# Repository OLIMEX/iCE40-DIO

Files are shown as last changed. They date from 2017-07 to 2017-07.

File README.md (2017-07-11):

# iCE40-DIO
Extension module for iCE40HX1K-EVB or iCE40HX8K-EVB.

iCE40-DIO adds 28 GPIOs to existing iCE40 boards. These signals can be set as inputs or outputs. 
The boards has a programmable DAC which can set the input voltage logic from 1.65 to 5.5V.

You can use the exported PDFs to access the schematic or the bill of materials. 

We used the latest KiCad night builds to create the design. Please use a new version KiCad to open it. 

License information should be found in LICENSE.txt

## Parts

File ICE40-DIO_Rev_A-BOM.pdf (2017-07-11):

ICE40-DIO_Rev_A | 08.04.2016
Quantity | Designation | Package | Designator
4 | 22uF/6.3V/0603 | C_0603 | C1,C3,C4,C6
10 | 100nF | C_0402 | C12,C13,C15,C2,C5,C10,C8,C9,C11,C14
1 | NA(100nF) | C_0402 | C7
2 | 2.2k | R_0402 | R1,R3
6 | 10k | R_0402 | R2,R4,R8,R9,R10,R11
1 | 10k/1% | R_0402 | R6
2 | 100k/1% | R_0402 | R5,R7
1 | FB0805/600R/2A | L_0805 | L1
1 | 1N5819(S4SOD-123) | SOD-123 | D1
2 | 74ALVC164245DL(SSOP48) | SSOP48 | U2,U3
1 | MCP1825-ADJE/DC(SOT-223-5) | SOT-223-5 | VR1
1 | MCP47A1T-A0E/LT(SC70-6) | SC70-6 | U1
4 | HN1x2(Opened) | HN1x2 | DIR1,DIR2,DIR3,DIR4
1 | BH10S | BH10S | UEXT1
1 | BH14S | BH14S | EXT1
1 | BH20S | BH20S | EXT2
1 | BH34R | BH34R | GPIO_Out1
1 | IDC34R | IDC34R_PCB | GPIO_In1

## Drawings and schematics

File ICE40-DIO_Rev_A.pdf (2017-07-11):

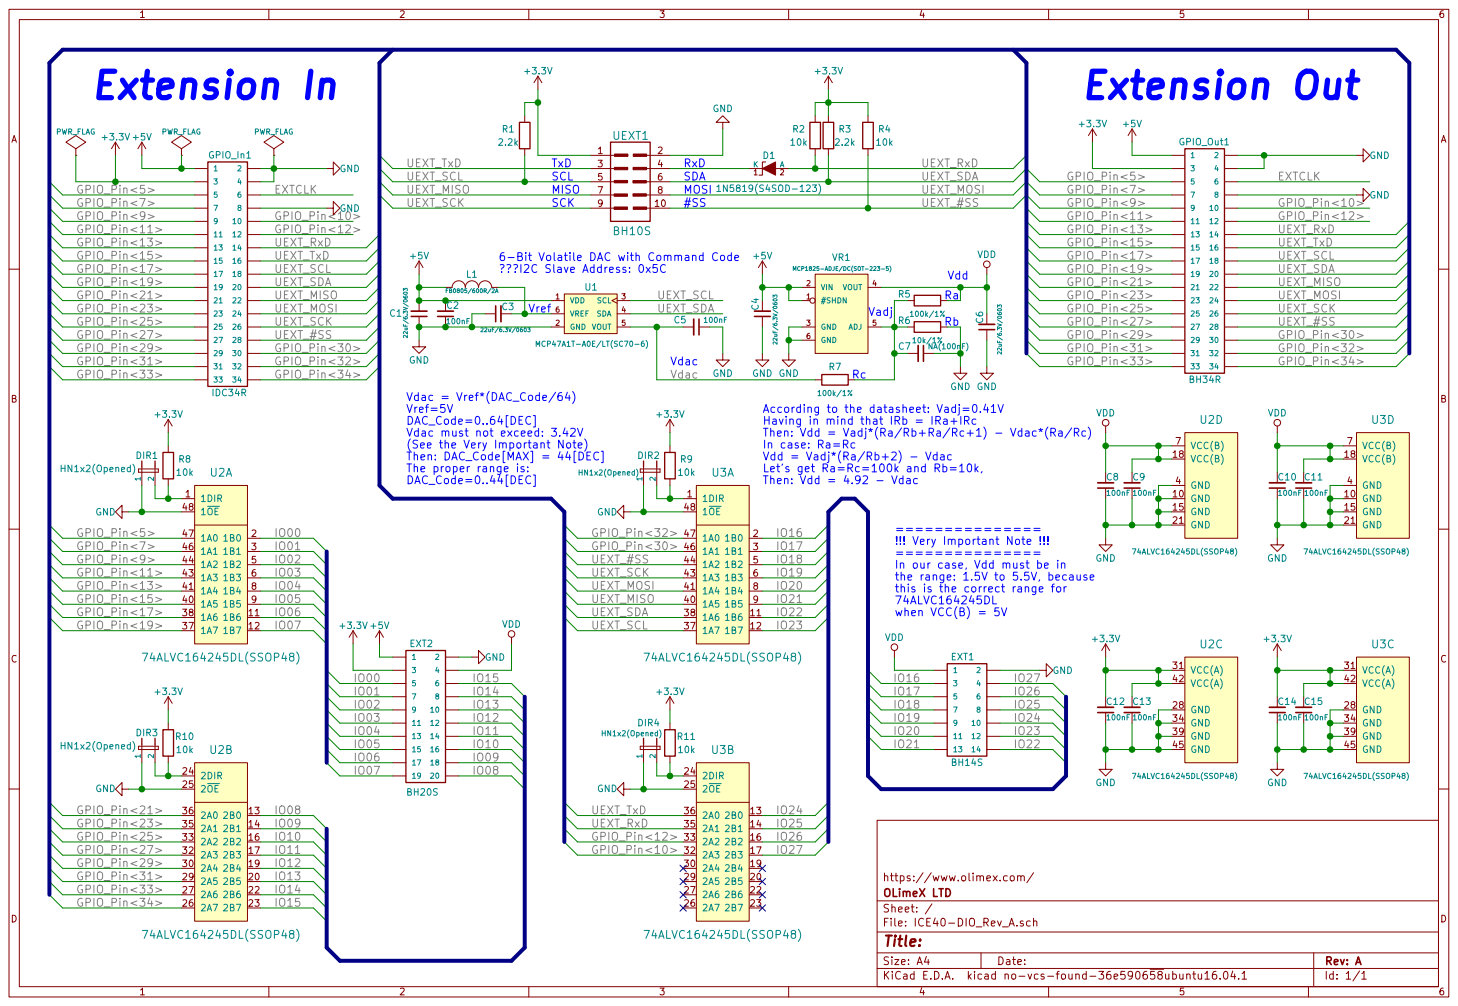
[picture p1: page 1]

6-Bit Volatile DAC with Command Code
I2C Slave Address: 0x5C

100k/1% According to the datasheet: Vadj=0.41V

Having in mind that IRb = IRa+IRc
Then: Vdd = Vadj*(Ra/Rb+Ra/Rc+1) - Vdac*(Ra/Rc)
In case: Ra=Rc Vdd = Vadj*(Ra/Rb+2) - Vdac

(See the Very Important Note)
Then: DAC_Code[MAX] = 44[DEC]
The proper range is:

!!! Very Important Note !!! ===============
In our case, Vdd must be in
the range: 1.5V to 5.5V, because
this is the correct range for
74ALVC164245DL
when VCC(B) = 5V

https://www.olimex.com/
File: ICE40-DIO_Rev_A.sch Sheet: / OLimeX LTD

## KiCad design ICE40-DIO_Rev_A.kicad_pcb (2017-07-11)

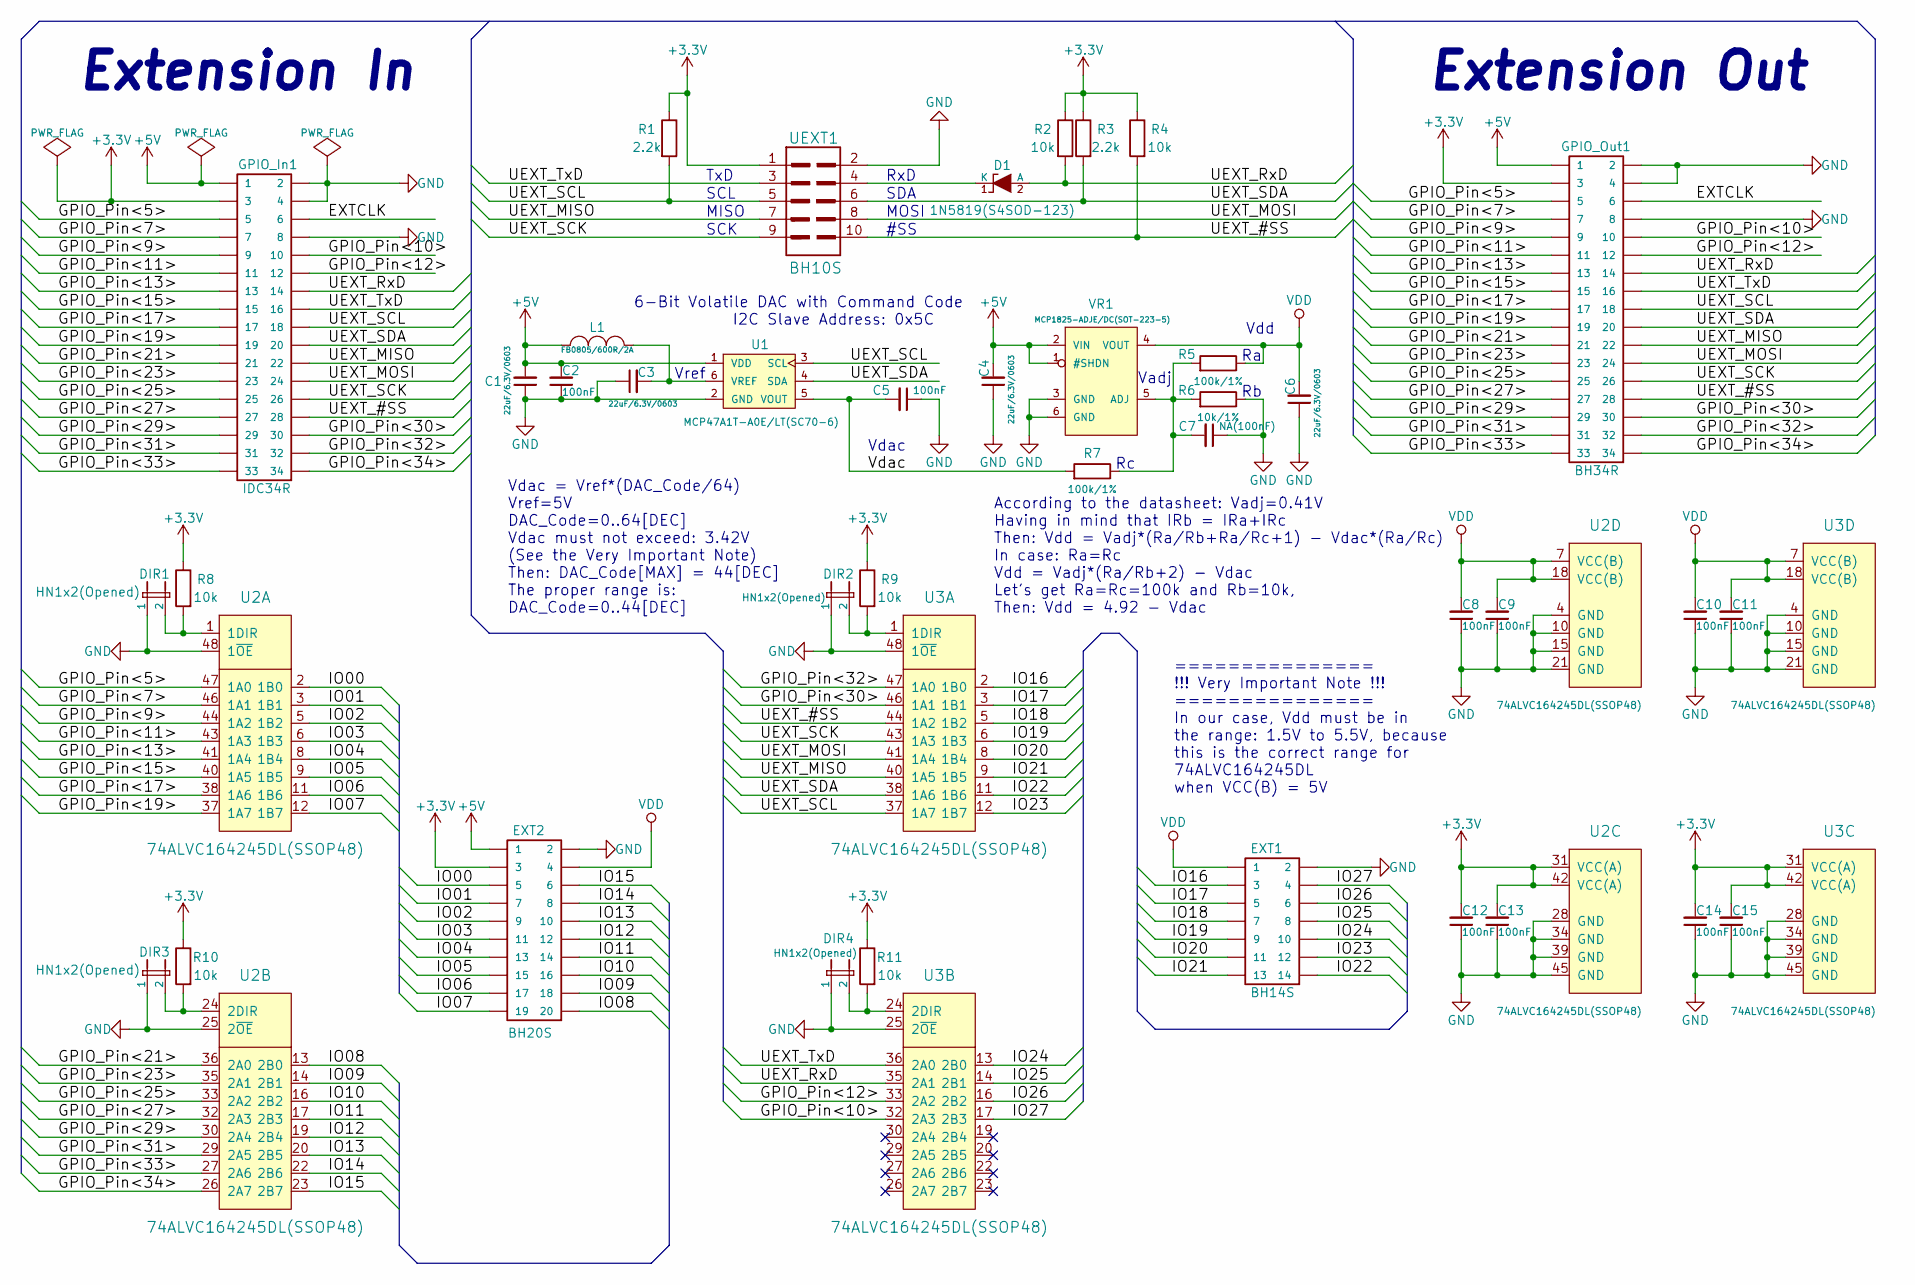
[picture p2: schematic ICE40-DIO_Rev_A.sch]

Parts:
C1, C3, C4, C6: 22uF/6.3V/0603; C_0603_5MIL_DWS
C2, C5, C8, C9, C10, C11, C12, C13, C14, C15: 100nF; C_0402_5MIL_DWS
C7: NA(100nF); C_0402_5MIL_DWS
D1: 1N5819(S4SOD-123); SOD-123_1C-2A_KA
DIR1, DIR2, DIR3, DIR4: HN1x2(Opened); HN1x2
EXT1: BH14S
EXT2: BH20S
GPIO_In1: IDC34R; IDC34R_PCB
GPIO_Out1: BH34R
L1: FB0805/600R/2A; L_0805_5MIL_DWS
R1, R3: 2.2k; R_0402_5MIL_DWS
R2, R4, R8, R9, R10, R11: 10k; R_0402_5MIL_DWS
R5, R7: 100k/1%; R_0402_5MIL_DWS
R6: 10k/1%; R_0402_5MIL_DWS
U1: MCP47A1T-A0E/LT(SC70-6); SC70-6_Pitch-0.65_2.00x2.10x1.00mm
U2, U3: 74ALVC164245DL(SSOP48); SSOP48_Pitch-0.635_16.00x10.40x2.80mm
UEXT1: BH10S
VR1: MCP1825-ADJE/DC(SOT-223-5); SOT-223-5_Pitch-1.27_6.50x7.00x1.80

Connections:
+3V3: C12.2, C13.2, C14.2, C15.2, EXT2.3, GPIO_In1.3, GPIO_Out1.3, R1.1, R2.1, R3.1, R4.1, R8.1, R9.1, R10.1, R11.1, U2.31 (VCC(A)), U2.42 (VCC(A)), U3.31 (VCC(A)), U3.42 (VCC(A)), UEXT1.1
+5V: C1.2, C2.2, C4.2, EXT2.1, GPIO_In1.1, GPIO_Out1.1, L1.2, U1.1 (VDD), VR1.1 (#SHDN), VR1.2 (VIN)
/EXTCLK: GPIO_In1.6, GPIO_Out1.6
/GPIO_Pin<5>: GPIO_In1.5, GPIO_Out1.5, U2.47 (1A0)
/GPIO_Pin<7>: GPIO_In1.7, GPIO_Out1.7, U2.46 (1A1)
/GPIO_Pin<9>: GPIO_In1.9, GPIO_Out1.9, U2.44 (1A2)
/GPIO_Pin<10>: GPIO_In1.10, GPIO_Out1.10, U3.32 (2A3)
/GPIO_Pin<11>: GPIO_In1.11, GPIO_Out1.11, U2.43 (1A3)
/GPIO_Pin<12>: GPIO_In1.12, GPIO_Out1.12, U3.33 (2A2)
/GPIO_Pin<13>: GPIO_In1.13, GPIO_Out1.13, U2.41 (1A4)
/GPIO_Pin<15>: GPIO_In1.15, GPIO_Out1.15, U2.40 (1A5)
/GPIO_Pin<17>: GPIO_In1.17, GPIO_Out1.17, U2.38 (1A6)
/GPIO_Pin<19>: GPIO_In1.19, GPIO_Out1.19, U2.37 (1A7)
/GPIO_Pin<21>: GPIO_In1.21, GPIO_Out1.21, U2.36 (2A0)
/GPIO_Pin<23>: GPIO_In1.23, GPIO_Out1.23, U2.35 (2A1)
/GPIO_Pin<25>: GPIO_In1.25, GPIO_Out1.25, U2.33 (2A2)
/GPIO_Pin<27>: GPIO_In1.27, GPIO_Out1.27, U2.32 (2A3)
/GPIO_Pin<29>: GPIO_In1.29, GPIO_Out1.29, U2.30 (2A4)
/GPIO_Pin<30>: GPIO_In1.30, GPIO_Out1.30, U3.46 (1A1)
/GPIO_Pin<31>: GPIO_In1.31, GPIO_Out1.31, U2.29 (2A5)
/GPIO_Pin<32>: GPIO_In1.32, GPIO_Out1.32, U3.47 (1A0)
/GPIO_Pin<33>: GPIO_In1.33, GPIO_Out1.33, U2.27 (2A6)
/GPIO_Pin<34>: GPIO_In1.34, GPIO_Out1.34, U2.26 (2A7)
/IO00: EXT2.5, U2.2 (1B0)
/IO01: EXT2.7, U2.3 (1B1)
/IO02: EXT2.9, U2.5 (1B2)
/IO03: EXT2.11, U2.6 (1B3)
/IO04: EXT2.13, U2.8 (1B4)
/IO05: EXT2.15, U2.9 (1B5)
/IO06: EXT2.17, U2.11 (1B6)
/IO07: EXT2.19, U2.12 (1B7)
/IO08: EXT2.20, U2.13 (2B0)
/IO09: EXT2.18, U2.14 (2B1)
/IO10: EXT2.16, U2.16 (2B2)
/IO11: EXT2.14, U2.17 (2B3)
/IO12: EXT2.12, U2.19 (2B4)
/IO13: EXT2.10, U2.20 (2B5)
/IO14: EXT2.8, U2.22 (2B6)
/IO15: EXT2.6, U2.23 (2B7)
/IO16: EXT1.3, U3.2 (1B0)
/IO17: EXT1.5, U3.3 (1B1)
/IO18: EXT1.7, U3.5 (1B2)
/IO19: EXT1.9, U3.6 (1B3)
/IO20: EXT1.11, U3.8 (1B4)
/IO21: EXT1.13, U3.9 (1B5)
/IO22: EXT1.14, U3.11 (1B6)
/IO23: EXT1.12, U3.12 (1B7)
/IO24: EXT1.10, U3.13 (2B0)
/IO25: EXT1.8, U3.14 (2B1)
/IO26: EXT1.6, U3.16 (2B2)
/IO27: EXT1.4, U3.17 (2B3)
/UEXT_#SS: GPIO_In1.28, GPIO_Out1.28, R4.2, U3.44 (1A2), UEXT1.10
/UEXT_MISO: GPIO_In1.22, GPIO_Out1.22, U3.40 (1A5), UEXT1.7
/UEXT_MOSI: GPIO_In1.24, GPIO_Out1.24, U3.41 (1A4), UEXT1.8
/UEXT_RxD: D1.2 (A), GPIO_In1.14, GPIO_Out1.14, R2.2, U3.35 (2A1)
/UEXT_SCK: GPIO_In1.26, GPIO_Out1.26, U3.43 (1A3), UEXT1.9
/UEXT_SCL: GPIO_In1.18, GPIO_Out1.18, R1.2, U1.3 (SCL), U3.37 (1A7), UEXT1.5
/UEXT_SDA: GPIO_In1.20, GPIO_Out1.20, R3.2, U1.4 (SDA), U3.38 (1A6), UEXT1.6
/UEXT_TxD: GPIO_In1.16, GPIO_Out1.16, U3.36 (2A0), UEXT1.3
/Vdac: C5.2, R7.2, U1.5 (VOUT)
GND: C1.1, C2.1, C3.1, C4.1, C5.1, C6.1, C7.1, C8.1, C9.1, C10.1, C11.1, C12.1, C13.1, C14.1, C15.1, DIR1.1, DIR2.1, DIR3.1, DIR4.1, EXT1.2, EXT2.2, GPIO_In1.2, GPIO_In1.4, GPIO_In1.8, GPIO_Out1.2, GPIO_Out1.4, GPIO_Out1.8, R6.1, U1.2 (GND), U2.4 (GND), U2.10 (GND), U2.15 (GND), U2.21 (GND), U2.25 (2~OE), U2.28 (GND), U2.34 (GND), U2.39 (GND), U2.45 (GND), U2.48 (1~OE), U3.4 (GND), U3.10 (GND), U3.15 (GND), U3.21 (GND), U3.25 (2~OE), U3.28 (GND), U3.34 (GND), U3.39 (GND), U3.45 (GND), U3.48 (1~OE), UEXT1.2, VR1.3 (GND), VR1.6 (GND)
unnamed: C3.2, L1.1, U1.6 (VREF)
unnamed: C7.2, R5.2, R6.2, R7.1, VR1.5 (ADJ)
unnamed: D1.1 (K), UEXT1.4
unnamed: DIR1.2, R8.2, U2.1 (1DIR)
unnamed: DIR2.2, R9.2, U3.1 (1DIR)
unnamed: DIR3.2, R10.2, U2.24 (2DIR)
unnamed: DIR4.2, R11.2, U3.24 (2DIR)
VDD: C6.2, C8.2, C9.2, C10.2, C11.2, EXT1.1, EXT2.4, R5.1, U2.7 (VCC(B)), U2.18 (VCC(B)), U3.7 (VCC(B)), U3.18 (VCC(B)), VR1.4 (VOUT)

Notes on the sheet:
Extension Out
Extension In
TxD
SCL
RxD
SDA
MISO
MOSI
SCK
#SS
According to the datasheet: Vadj=0.41V Having in mind that IRb = IRa+IRc Then: Vdd = Vadj*(Ra/Rb+Ra/Rc+1) - Vdac*(Ra/Rc) In case: Ra=Rc Vdd = Vadj*(Ra/Rb+2) - Vdac Let's get Ra=Rc=100k and Rb=10k, Then: Vdd = 4.92 - Vdac
Vdd
Vadj
Vdac
Vdac = Vref*(DAC_Code/64) Vref=5V DAC_Code=0..64[DEC] Vdac must not exceed: 3.42V (See the Very Important Note) Then: DAC_Code[MAX] = 44[DEC] The proper range is: DAC_Code=0..44[DEC]
Vref
=============== !!! Very Important Note !!! =============== In our case, Vdd must be in the range: 1.5V to 5.5V, because this is the correct range for 74ALVC164245DL when VCC(B) = 5V
6-Bit Volatile DAC with Command Code I2C Slave Address: 0x5C

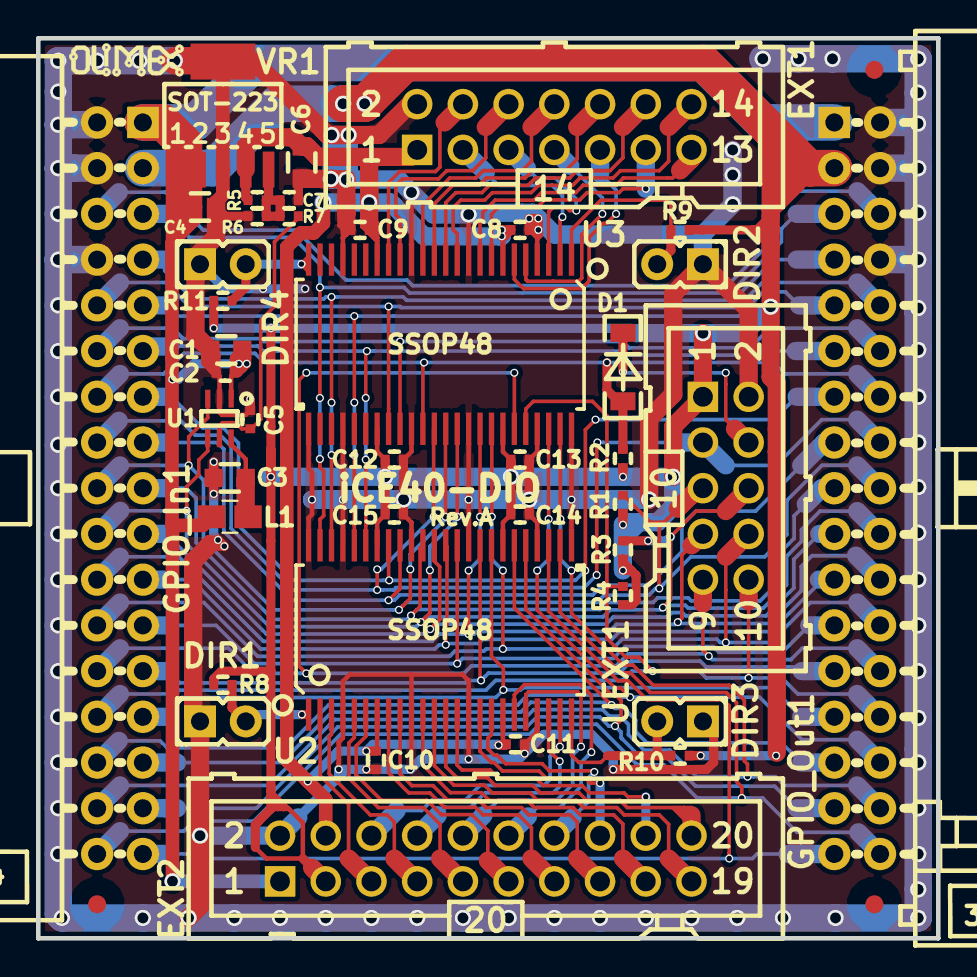
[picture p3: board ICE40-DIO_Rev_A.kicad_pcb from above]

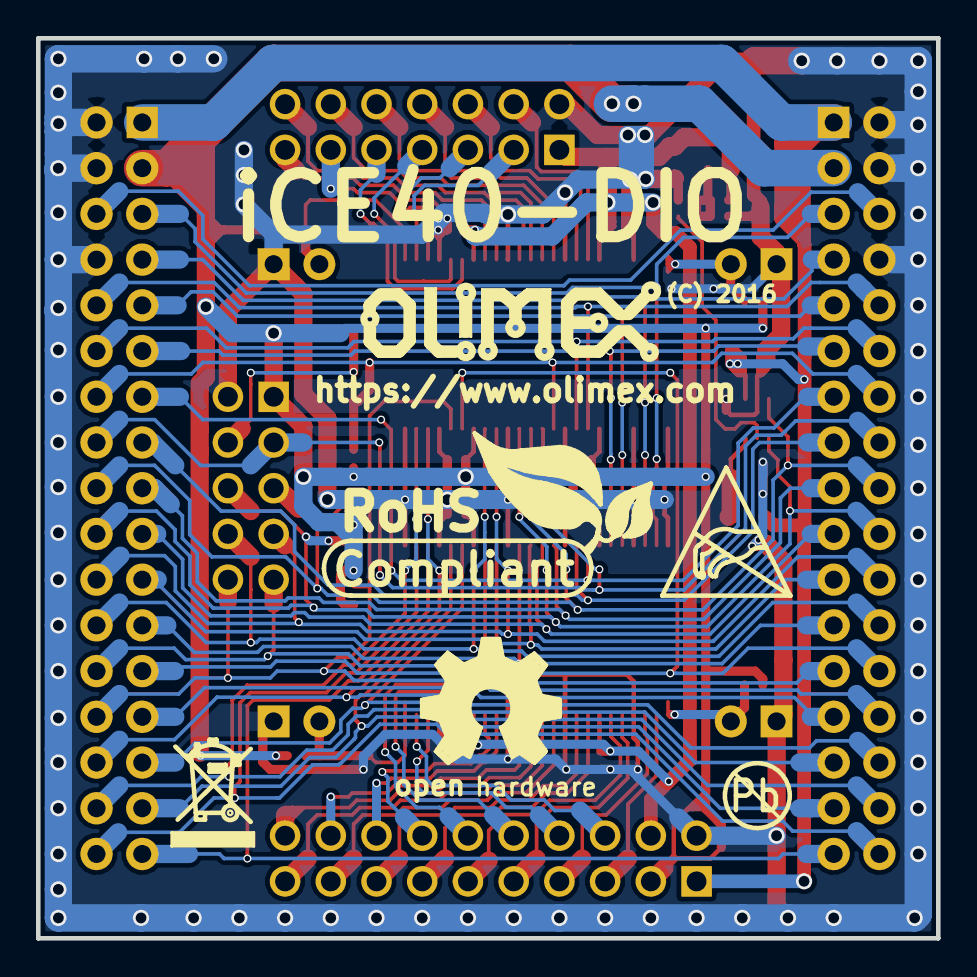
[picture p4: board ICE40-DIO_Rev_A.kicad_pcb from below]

Board: 2 copper layers, 50.0 x 50.0 mm, 43 parts (2 on the bottom side), 69 nets.

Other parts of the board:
Ref**: Val**; LOGO_ANTISTATIC_1
Ref**#2: Val**; LOGO_ROHS_1

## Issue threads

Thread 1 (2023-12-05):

Software

rog77, 2023-12-05:
I recently purchased a couple of these units to go with your fpga board because your website stated there was software support for: 100Mhz logic analyzer & SigRok API - could you please point me at the relevant files/links to.use the advertised software, as I can't see it either on your website or in your github repositories.  Thanks.

DanKoloff, 2023-12-06:
We don't have any demo software for iCE40-DIO. The "100Mhz logic analyzer" and "SigRok API" lines were never links, they were just placeholders texts stating the intention to publish such examples. This never happened, unfortunately.

rog77, 2023-12-06:
Well thanks for getting back to me anyway. I had ordered these and some of the ADC/DAC boards too, whilst I have your attention can you please point me ant any example software for those? I realise that's a separate repo... I would have asked on your forum but people don't seem to respond as far as I can see. Thanks again.

DanKoloff, 2023-12-12:
It is the same situation for iCE40-ADC and iCE40-DAC - the tests here seem to be simple bit bang and we haven no official demo code. The only chance is if some other customer published something about these boards. Else you'd have to start from scratch and the schematics.

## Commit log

2017-07-11 update
    relocate
    [ICE40-DIO_Rev_A.kicad_pcb, ICE40-DIO_Rev_A.sch]
2017-07-11 Update
    Changed trace names
    [ICE40-DIO_Rev_A-BOM.ods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]

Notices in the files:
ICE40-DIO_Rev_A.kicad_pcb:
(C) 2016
